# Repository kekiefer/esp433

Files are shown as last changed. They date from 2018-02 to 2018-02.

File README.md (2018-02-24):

# ESP433

KiCad source to build an ESP8266 WiFi to 433MHz ASK/OOK bridge

## How to Build One

This board is available on Oshpark: https://oshpark.com/shared_projects/5Debb7gg

The bom has been exported here as esp433.csv

## Key Components

* ESP12s - ESP8266 surface mount WiFi module
* Maxim MAX7044AKA+T - 300 ~ 450 MHz ASK/OOK RF transmitter
* Mean Well IRM-02-5 - AC to DC Power Supply 5V 2W
* PolyCase GS-2315 - Plug-in project enclosure

## More Information

A project writeup is available on hackaday.io: https://hackaday.io/project/63004-esp433-wifi-to-433mhz-bridge

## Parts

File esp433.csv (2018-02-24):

Source: | /Code/KieferWare/esp433/esp433.sch
Date: | Saturday, February 24, 2018 'PMt' 02:17:15 PM
Tool: | Eeschema 4.0.7
Generator: | /Applications/Kicad/kicad.app/Contents/SharedSupport/plugins/bom_csv_grouped_by_value_with_fp.py
Component Count: | 52
Ref | Qnty | Value | Cmp name | Footprint | Description | Vendor | Vendorpart
AE1, | 1 | Antenna | Antenna | esp433:W3127 | Antenna symbol |  | 553-1696-ND
C1, C2, | 2 | 1u | C | Capacitors_SMD:C_0603 | Unpolarized capacitor |  | 587-1242-1-ND
C3, C18, C19, | 3 | DNP | C | Capacitors_SMD:C_0603 | Unpolarized capacitor
C4, | 1 | 220p | C | Capacitors_SMD:C_0603 | Unpolarized capacitor |  | 1276-1145-1-ND
C5, | 1 | 0.01u | C | Capacitors_SMD:C_0603 | Unpolarized capacitor |  | 399-1091-1-ND
C7, C6, C15, C16, | 4 | 12p | C | Capacitors_SMD:C_0603 | Unpolarized capacitor |  | 1276-1254-1-ND
C9, | 1 | 10n | C | Capacitors_SMD:C_0603 | Unpolarized capacitor |  | 445-1311-1-ND
C10, C11, | 2 | 47p | C | Capacitors_SMD:C_0603 | Unpolarized capacitor |  | 445-5636-1-ND
C13, | 1 | 4.7u | C | Capacitors_SMD:C_0603 | Unpolarized capacitor |  | 1276-1045-1-ND
C14, C12, C8, | 3 | 100n | C | Capacitors_SMD:C_0603 | Unpolarized capacitor |  | 445-5667-1-ND
C17, | 1 | 15p | C | Capacitors_SMD:C_0603 | Unpolarized capacitor |  | 1276-2190-1-ND
D1, | 1 | D | D | Diodes_SMD:D_SOD-123F | Diode |  | MBR120VLSFT3GOSCT-ND
D2, | 1 | LED | LED | LEDs:LED_0603 | LED generic |  | 732-4981-1-ND
J1, | 1 | USB_OTG | USB_OTG | Connectors_USB:USB_Micro-B_Vertical_Molex-105133-0001 | USB mini/micro connector |  | WM9734CT-ND
J2, | 1 | CONN_01X03 | CONN_01X03 | Pin_Headers:Pin_Header_Angled_1x03 |  |  | S5439-ND
L1, | 1 | Ferrite_Bead | Ferrite_Bead | Inductors_SMD:L_0805 | Ferrite bead |  | 240-2389-1-ND
L2, | 1 | 27nH | L | Inductors_SMD:L_0603 | Inductor |  | 490-6879-1-ND
L3, | 1 | 16nH | L | Inductors_SMD:L_0603 | Inductor |  | 490-6868-1-ND
MK1, MK2, | 2 | Mounting_Hole_PAD | Mounting_Hole_PAD | Wire_Pads:SolderWirePad_single_2mmDrill | Mounting Hole with connection
MK3, MK4, MK5, MK6, | 4 | Mounting_Hole | Mounting_Hole | Mounting_Holes:MountingHole_3.2mm_M3 | Mounting Hole without connection
Q1, | 1 | MBT2222ADW1T1 | MBT2222ADW1T1 | TO_SOT_Packages_SMD:SOT-363_SC-70-6 | 65V Vce, 100mA IC, Dual NPN/NPN Transistors, SOT-363 |  | MBT2222ADW1T1GOSCT-ND
R1, R5, R2, R3, R10, | 5 | 10K | R | Resistors_SMD:R_0603 | Resistor |  | 311-10KGRCT-ND
R4, | 1 | 4.7K | R | Resistors_SMD:R_0603 | Resistor |  | 311-4.7KGRCT-ND
R6, | 1 | R_Variable | R_Variable | Potentiometers:Potentiometer_Trimmer_Vishay_TS53YL | variable Resistor (Rheostat) |  | TS53YL-5.0KCT-ND
R7, R8, | 2 | 27 | R | Resistors_SMD:R_0603 | Resistor |  | 311-27GRCT-ND
R9, R11, | 2 | 1K | R | Resistors_SMD:R_0603 | Resistor |  | 311-1.0KGRCT-ND
SW1, | 1 | SW_Push | SW_Push | Buttons_Switches_SMD:SW_SPST_B3U-1000P | Push button switch, generic, two pins |  | SW1020CT-ND
U1, | 1 | IRM-02-5 | IRM-02-5 | Converters_DCDC_ACDC:ACDC-Converter_MeanWell-IRM-02-x | 3.3V 2W miniature AC-DC module-type power supply MeanWell | mouser | 709-IRM02-5
U2, | 1 | AP2127K-3.3 | AP2127K-3.3 | TO_SOT_Packages_SMD:SOT-23-5 | 150mA low dropout linear regulator, wide input voltage range, 1.5V fixed positive output, SOT-23-5 package |  | AP2112K-3.3TRG1DICT-ND
U3, | 1 | MAX7044 | MAX7044 | TO_SOT_Packages_SMD:SOT-23-8 |  |  | MAX7044AKA+TCT-ND
U4, | 1 | ESP-12E | ESP-12E | ESP8266:ESP-12E_SMD | ESP8266 ESP-12E module, 22 pins, 2mm, PCB antenna | adafruit | 2491
U5, | 1 | FT231XS | FT231XS | SMD_Packages:SSOP-20 | Full Speed USB to Full Handshake UART, SSOP-20 |  | 768-1129-1-ND
Y1, | 1 | Crystal | Crystal | Crystals:Crystal_HC49-U_Vertical | Two pin crystal |  | 887-2013-ND

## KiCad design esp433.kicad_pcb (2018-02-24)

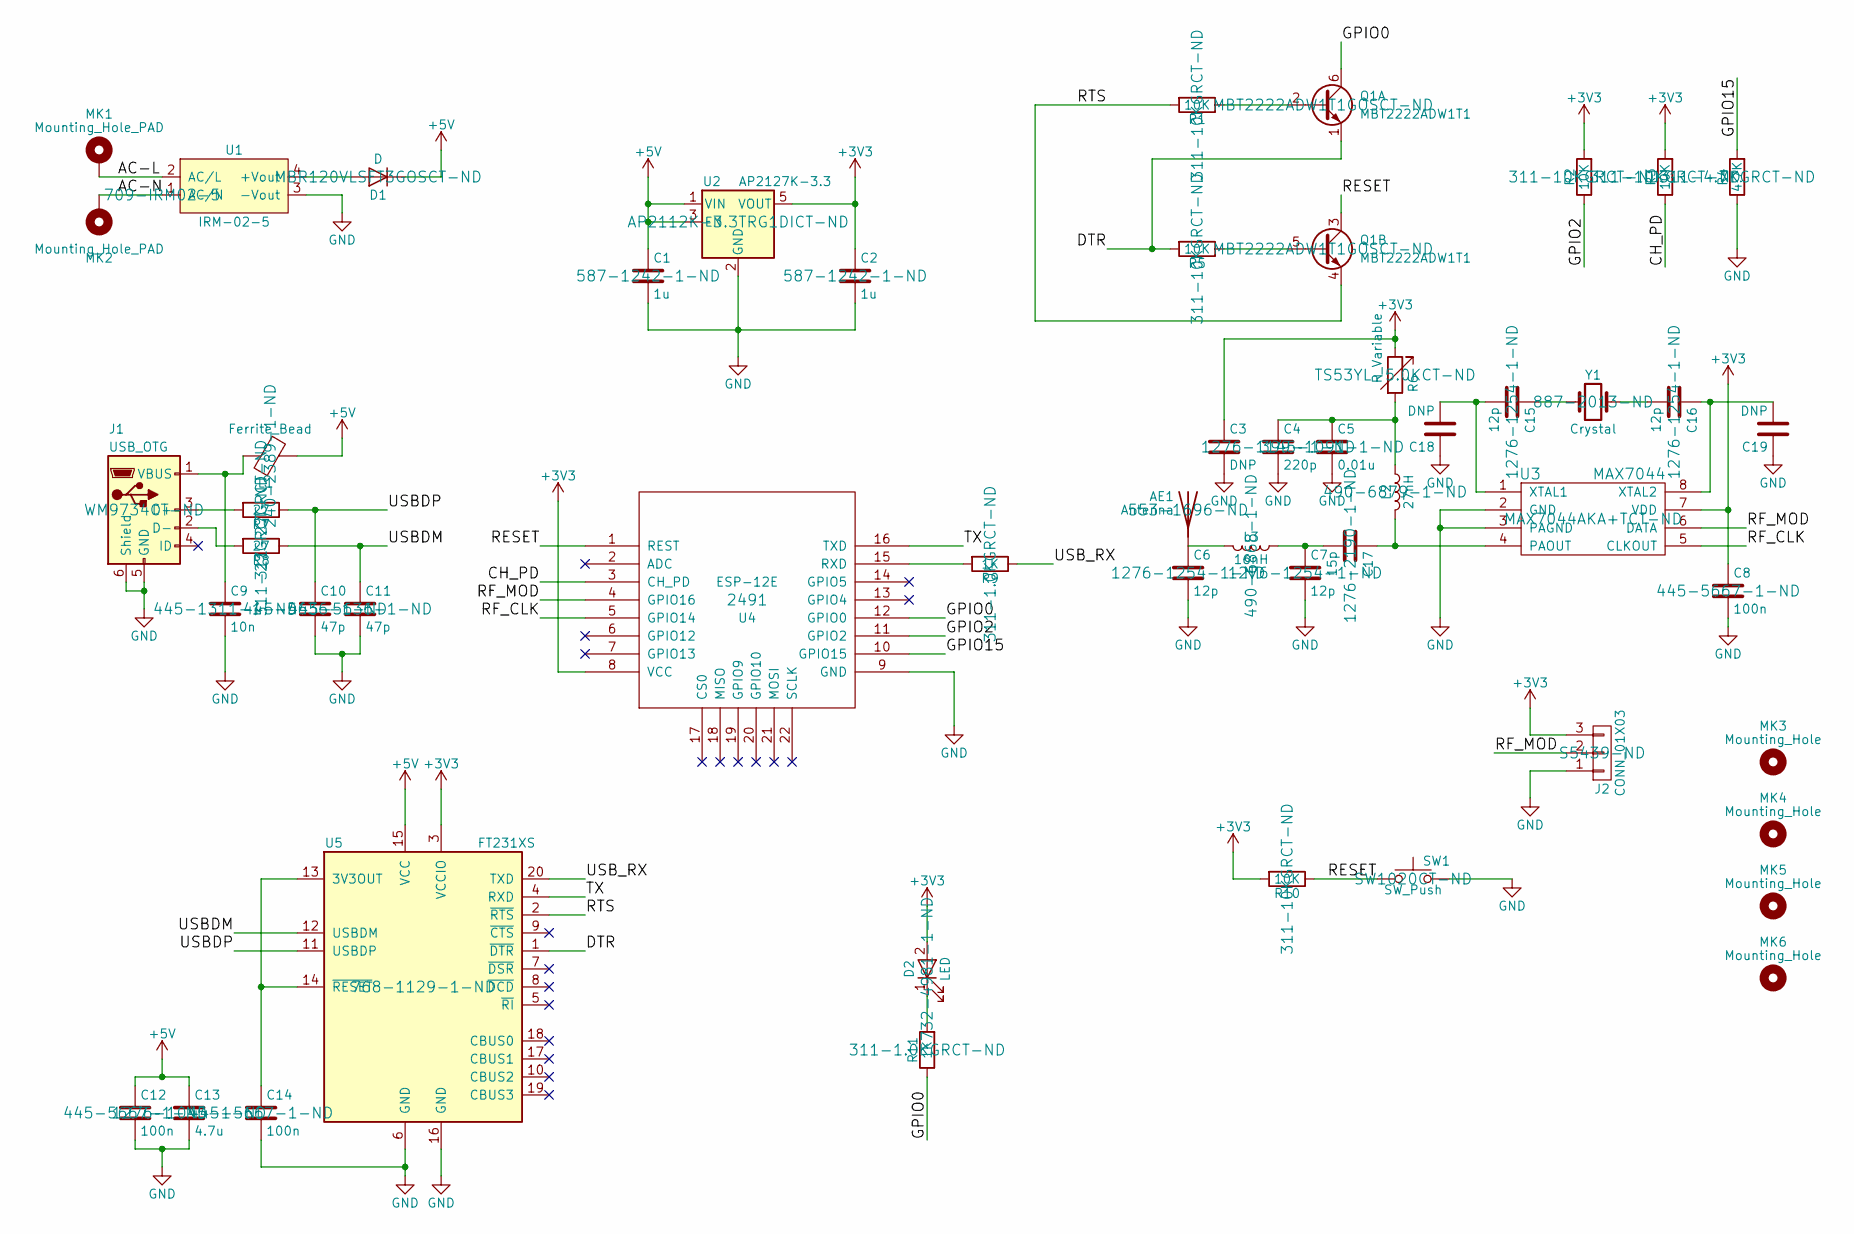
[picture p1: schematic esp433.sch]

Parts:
AE1: Antenna; W3127
C1, C2: 1u; C_0603
C3, C18, C19: DNP; C_0603
C4: 220p; C_0603
C5: 0.01u; C_0603
C6, C7, C15, C16: 12p; C_0603
C8, C12, C14: 100n; C_0603
C9: 10n; C_0603
C10, C11: 47p; C_0603
C13: 4.7u; C_0603
C17: 15p; C_0603
D1: D; D_SOD-123F
D2: LED; LED_0603
J1: USB_OTG; USB_Micro-B_Vertical_Molex-105133-0001
J2: CONN_01X03; Pin_Header_Angled_1x03
L1: Ferrite_Bead; L_0805
L2: 27nH; L_0603
L3: 16nH; L_0603
MK1, MK2: Mounting_Hole_PAD; SolderWirePad_single_2mmDrill
MK3, MK4, MK5, MK6: Mounting_Hole; MountingHole_3.2mm_M3
Q1: MBT2222ADW1T1; SOT-363_SC-70-6
R1, R2, R3, R5, R10: 10K; R_0603
R4: 4.7K; R_0603
R6: R_Variable; Potentiometer_Trimmer_Vishay_TS53YL
R7, R8: 27; R_0603
R9, R11: 1K; R_0603
SW1: SW_Push; SW_SPST_B3U-1000P
U1: IRM-02-5; ACDC-Converter_MeanWell-IRM-02-x
U2: AP2127K-3.3; SOT-23-5
U3: MAX7044; SOT-23-8
U4: ESP-12E; ESP-12E_SMD
U5: FT231XS; SSOP-20
Y1: Crystal; Crystal_HC49-U_Vertical

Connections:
+3V3: C2.1, C3.1, C8.1, D2.2 (A), J2.3, R2.2, R3.2, R6.1, R10.2, U2.5 (VOUT), U3.7 (VDD), U4.8 (VCC), U5.3 (VCCIO)
+5V: C1.1, C12.1, C13.1, D1.1 (K), L1.2, U2.1 (VIN), U2.3 (EN), U5.15 (VCC)
/AC-L: MK1.1, U1.2 (AC/L)
/AC-N: MK2.1, U1.1 (AC/N)
/CH_PD: R3.1, U4.3 (CH_PD)
/DTR: Q1.1 (E1), R5.2, U5.1 (~DTR)
/GPIO0: Q1.6 (C1), R11.1, U4.12 (GPIO0)
/GPIO2: R2.1, U4.11 (GPIO2)
/GPIO15: R4.2, U4.10 (GPIO15)
/RESET: Q1.3 (C2), R10.1, SW1.1, U4.1 (REST)
/RF_CLK: U3.5 (CLKOUT), U4.5 (GPIO14)
/RF_MOD: J2.2, U3.6 (DATA), U4.4 (GPIO16)
/RTS: Q1.4 (E2), R1.2, U5.2 (~RTS)
/TX: U4.16 (TXD), U5.4 (RXD)
/USBDM: C11.1, R8.1, U5.12 (USBDM)
/USBDP: C10.1, R7.1, U5.11 (USBDP)
/USB_RX: R9.1, U5.20 (TXD)
GND: C1.2, C2.2, C3.2, C4.2, C5.2, C6.2, C7.2, C8.2, C9.2, C10.2, C11.2, C12.2, C13.2, C14.2, C18.1, C19.1, J1.5 (GND), J1.6 (Shield), J2.1, R4.1, SW1.2, U1.3 (-Vout), U2.2 (GND), U3.2 (GND), U3.3 (PAGND), U4.9 (GND), U5.6 (GND), U5.16 (GND)
unnamed: AE1.1, C6.1, L3.2
unnamed: C4.1, C5.1, L2.1, R6.2
unnamed: C9.1, J1.1 (VBUS), L1.1
unnamed: C14.1, U5.13 (3V3OUT), U5.14 (~RESET)
unnamed: C15.1, Y1.1
unnamed: C15.2, C18.2, U3.1 (XTAL1)
unnamed: C16.1, C19.2, U3.8 (XTAL2)
unnamed: C16.2, Y1.2
unnamed: C17.1, L2.2, U3.4 (PAOUT)
unnamed: C7.1, C17.2, L3.1
unnamed: D1.2 (A), U1.4 (+Vout)
unnamed: D2.1 (K), R11.2
unnamed: J1.2 (D-), R8.2
unnamed: J1.3 (D+), R7.2
unnamed: Q1.2 (B1), R1.1
unnamed: Q1.5 (B2), R5.1
unnamed: R9.2, U4.15 (RXD)

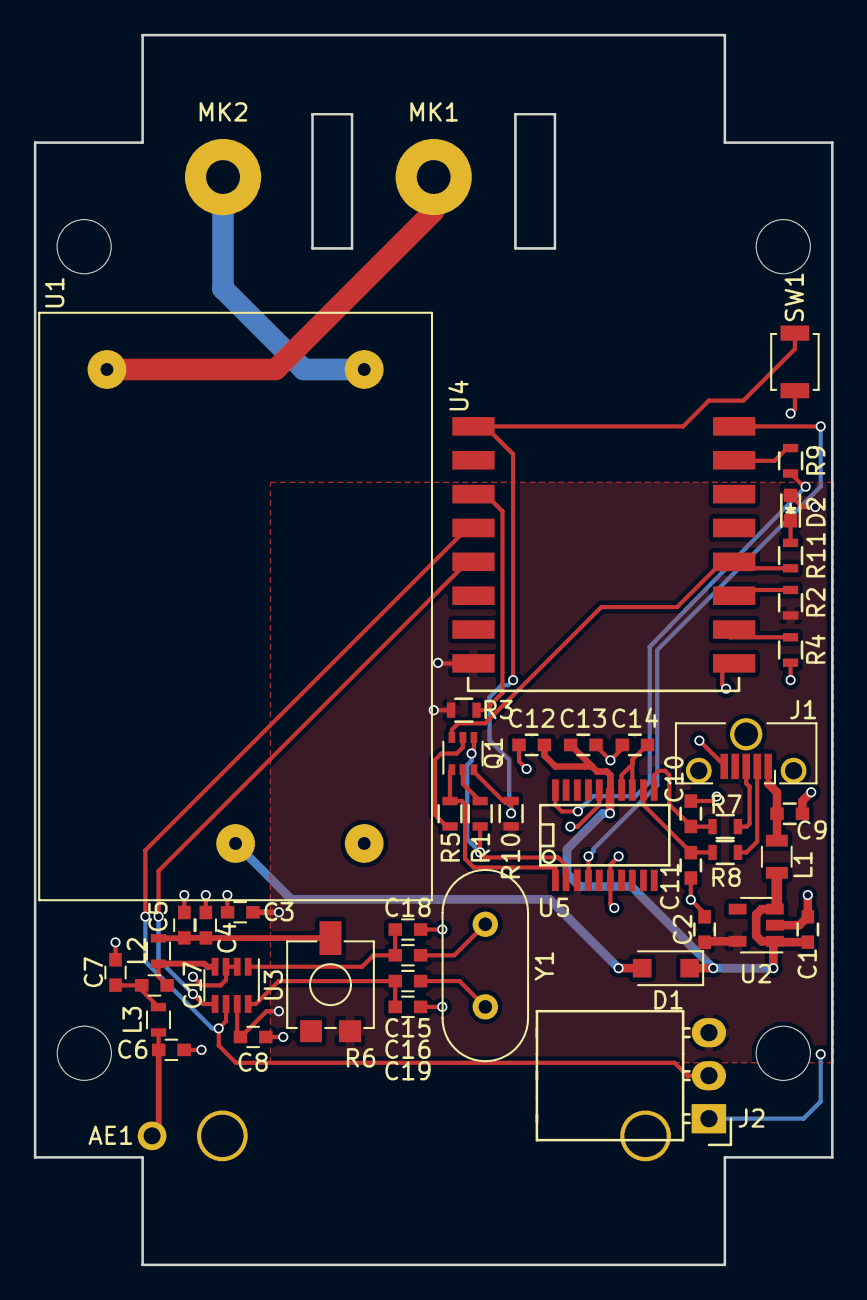
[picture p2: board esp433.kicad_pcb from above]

Board: 2 copper layers, 47.1 x 72.6 mm, 52 parts (0 on the bottom side), 35 nets.

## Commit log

2018-02-04 Add footprint for ant-433-heth
2018-02-04 Add rf circuit
    [esp433.kicad_pcb, esp433.sch]
2018-02-04 Rearrange silk
    [esp433.kicad_pcb]
2018-02-04 Rearrange filtering according to datasheet
    [esp433.kicad_pcb, esp433.sch]
2018-02-04 Correct hot/neutral labeling on power input
    [esp433.kicad_pcb]
2018-02-23 Rework to fix oscillator and antenna circuit
    [esp433.kicad_pcb, esp433.sch]
2018-02-23 Fix footprint for D1
    [esp433.kicad_pcb, esp433.sch]
2018-02-23 Add bom file
    [esp433.csv]
2018-02-24 Add some dnp footprints for additional oscillator parallel capacitance
    [esp433.kicad_pcb, esp433.sch]
2018-02-24 Pick inductors specified by MAX7044 reference design
    [esp433.sch]
2018-02-24 More parts to match reference design
    [esp433.sch]
2018-02-24 Update BOM for recent component changes to match MAX7044 reference
    [esp433.csv]
2018-02-24 Updated netlist in pcb, no change to layout
    [esp433.kicad_pcb]
2018-02-24 Update oshpark board link to r2
